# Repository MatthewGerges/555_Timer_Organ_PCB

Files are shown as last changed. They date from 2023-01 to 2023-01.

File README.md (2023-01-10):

# 555 Timer Piano PCB


- This project was created using Altium CircuitMaker. All design files including the 3D model can be viewed here: 
https://365.altium.com/files/4F6F4C2E-66A3-4076-8B9E-142F36BC1FB1

- This PCB uses a 555 timer to generate sounds part of the diatonic scale on a piano. 
- One of the resistors used to set the frequency of the clock signal is fixed. 
- The resistor whose connected momentary switch is pressed acts as the other element that dictates the frequency of the clock signal. 
- The output of the clock then feeds to an NPN transistor that acts as an audio amplifier. 
- The amplified signal is then run through a speaker so the user can hear the piano note.

Video Demo: 
https://www.loom.com/share/736d4f29e4ee4808afbea287dc831833

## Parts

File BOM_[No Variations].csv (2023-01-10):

Comment | Description | Designator | Quantity | Man. Part Number
Memory Protection Devices BH9VPC | 9V cell holder w/ PC pins (80 pcs per tray) |  | 1
FG11X7R1C226MRT06 | Commercial Grade, Halogen Free Dipped Radial / Ammo Pack | C1 | 1
Panasonic ECA-1HM100B | Cap Aluminum 10uF 50V 20% (2.5v6 or 2.5 X 11mm) Radial Aluminum Cylindrical Can p=5x6 mm 65mA 2000 hr 85°C Ammo Pack | C2 | 1
Vishay A104K15X7RF5UAA | Cap Ceramic 0.1uF 50V X7R 10% Axial 125°C Ammo Pack | C3, C4, C5, C6 | 4
Panasonic ECA-1HM100B 100mF | Cap Aluminum 10uF 50V 20% (2.5v6 or 2.5 X 11mm) Radial Aluminum Cylindrical Can p=5x6 mm 65mA 2000 hr 85°C Ammo Pack | C7 | 1
100 mF | Cap Aluminum 10uF 50V 20% (2.5v6 or 2.5 X 11mm) Radial Aluminum Cylindrical Can p=5x6 mm 65mA 2000 hr 85°C Ammo Pack | C8 | 1
Lumex SSL-LX5093PGD | Green 5 mm 60° Diffused 30 mcd 2.2 V Through Hole LED - T-1¾ | D1 | 1
"Flyback/Inductive Kick Diode" | 1N4001 Series 1 A 400 V Through-Hole Rectifying Diode - DO-41 | D2 | 1
Fairchild Semiconductor KSP43TA | Trans GP BJT NPN 200V 0.5A 3-Pin TO-92 Ammo | Q1 | 1
Yageo CFR-25JR-52-270R | CFR Series 0.25 W 470 Ohm ±5 % -350 to 500 ppm/°C Carbon Film Resistor | R1 | 1
27.7k | CFR Series 0.25 W 470 Ohm ±5 % -350 to 500 ppm/°C Carbon Film Resistor | R2 | 1
25.5k | CFR Series 0.25 W 470 Ohm ±5 % -350 to 500 ppm/°C Carbon Film Resistor | R3 | 1
24.0k | CFR Series 0.25 W 470 Ohm ±5 % -350 to 500 ppm/°C Carbon Film Resistor | R4 | 1
22.1 | CFR Series 0.25 W 470 Ohm ±5 % -350 to 500 ppm/°C Carbon Film Resistor | R5 | 1
21.0 | CFR Series 0.25 W 470 Ohm ±5 % -350 to 500 ppm/°C Carbon Film Resistor | R6 | 1
20.0 | CFR Series 0.25 W 470 Ohm ±5 % -350 to 500 ppm/°C Carbon Film Resistor | R7 | 1
18.7 | CFR Series 0.25 W 470 Ohm ±5 % -350 to 500 ppm/°C Carbon Film Resistor | R8 | 1
17.8 | CFR Series 0.25 W 470 Ohm ±5 % -350 to 500 ppm/°C Carbon Film Resistor | R9 | 1
16.5 | CFR Series 0.25 W 470 Ohm ±5 % -350 to 500 ppm/°C Carbon Film Resistor | R10 | 1
16.0 | CFR Series 0.25 W 470 Ohm ±5 % -350 to 500 ppm/°C Carbon Film Resistor | R11 | 1
15.0 | CFR Series 0.25 W 470 Ohm ±5 % -350 to 500 ppm/°C Carbon Film Resistor | R12 | 1
14.0 | CFR Series 0.25 W 470 Ohm ±5 % -350 to 500 ppm/°C Carbon Film Resistor | R13 | 1
1.4k | CFR Series 0.25 W 470 Ohm ±5 % -350 to 500 ppm/°C Carbon Film Resistor | R14 | 1
10k | CFR Series 0.25 W 470 Ohm ±5 % -350 to 500 ppm/°C Carbon Film Resistor | R15 | 1
1k | CFR Series 0.25 W 470 Ohm ±5 % -350 to 500 ppm/°C Carbon Film Resistor | R16 | 1
TSW-102-22-L-S-RA | 0.025" SQ Post Header, Through-hole, Right Angle, -55 to 125 degC, 2.54 mm Pitch, 2-Pin, Male, RoHS | SPK1 | 1
E-Switch EG1218 | Slide Switch, 500 V, -20 to 70 degC, 3-Pin THD, RoHS | SW1 | 1
Panasonic EVQ-21405R | Switch Tactile N.O. SPST Round Button PC Pins 0.02A 15VDC 1.3N Thru-Hole Radial T/R | SW2, SW3, SW4, SW5, SW6, SW7, SW8, SW9, SW10, SW11, SW12, SW13 | 12
2x2mm-pad | Raychem; SMT Circuit probe pad, 0805, 0R0 RCT | TP_5V, TP_GND1, TP_SIG | 3
MCP1702-5002E/TO | 250 mA Low Quiescent Current LDO Regulator, 3-Pin TO-92, Extended TemperatureBAG | U1 | 1
555 Custom | timer | U2 | 1

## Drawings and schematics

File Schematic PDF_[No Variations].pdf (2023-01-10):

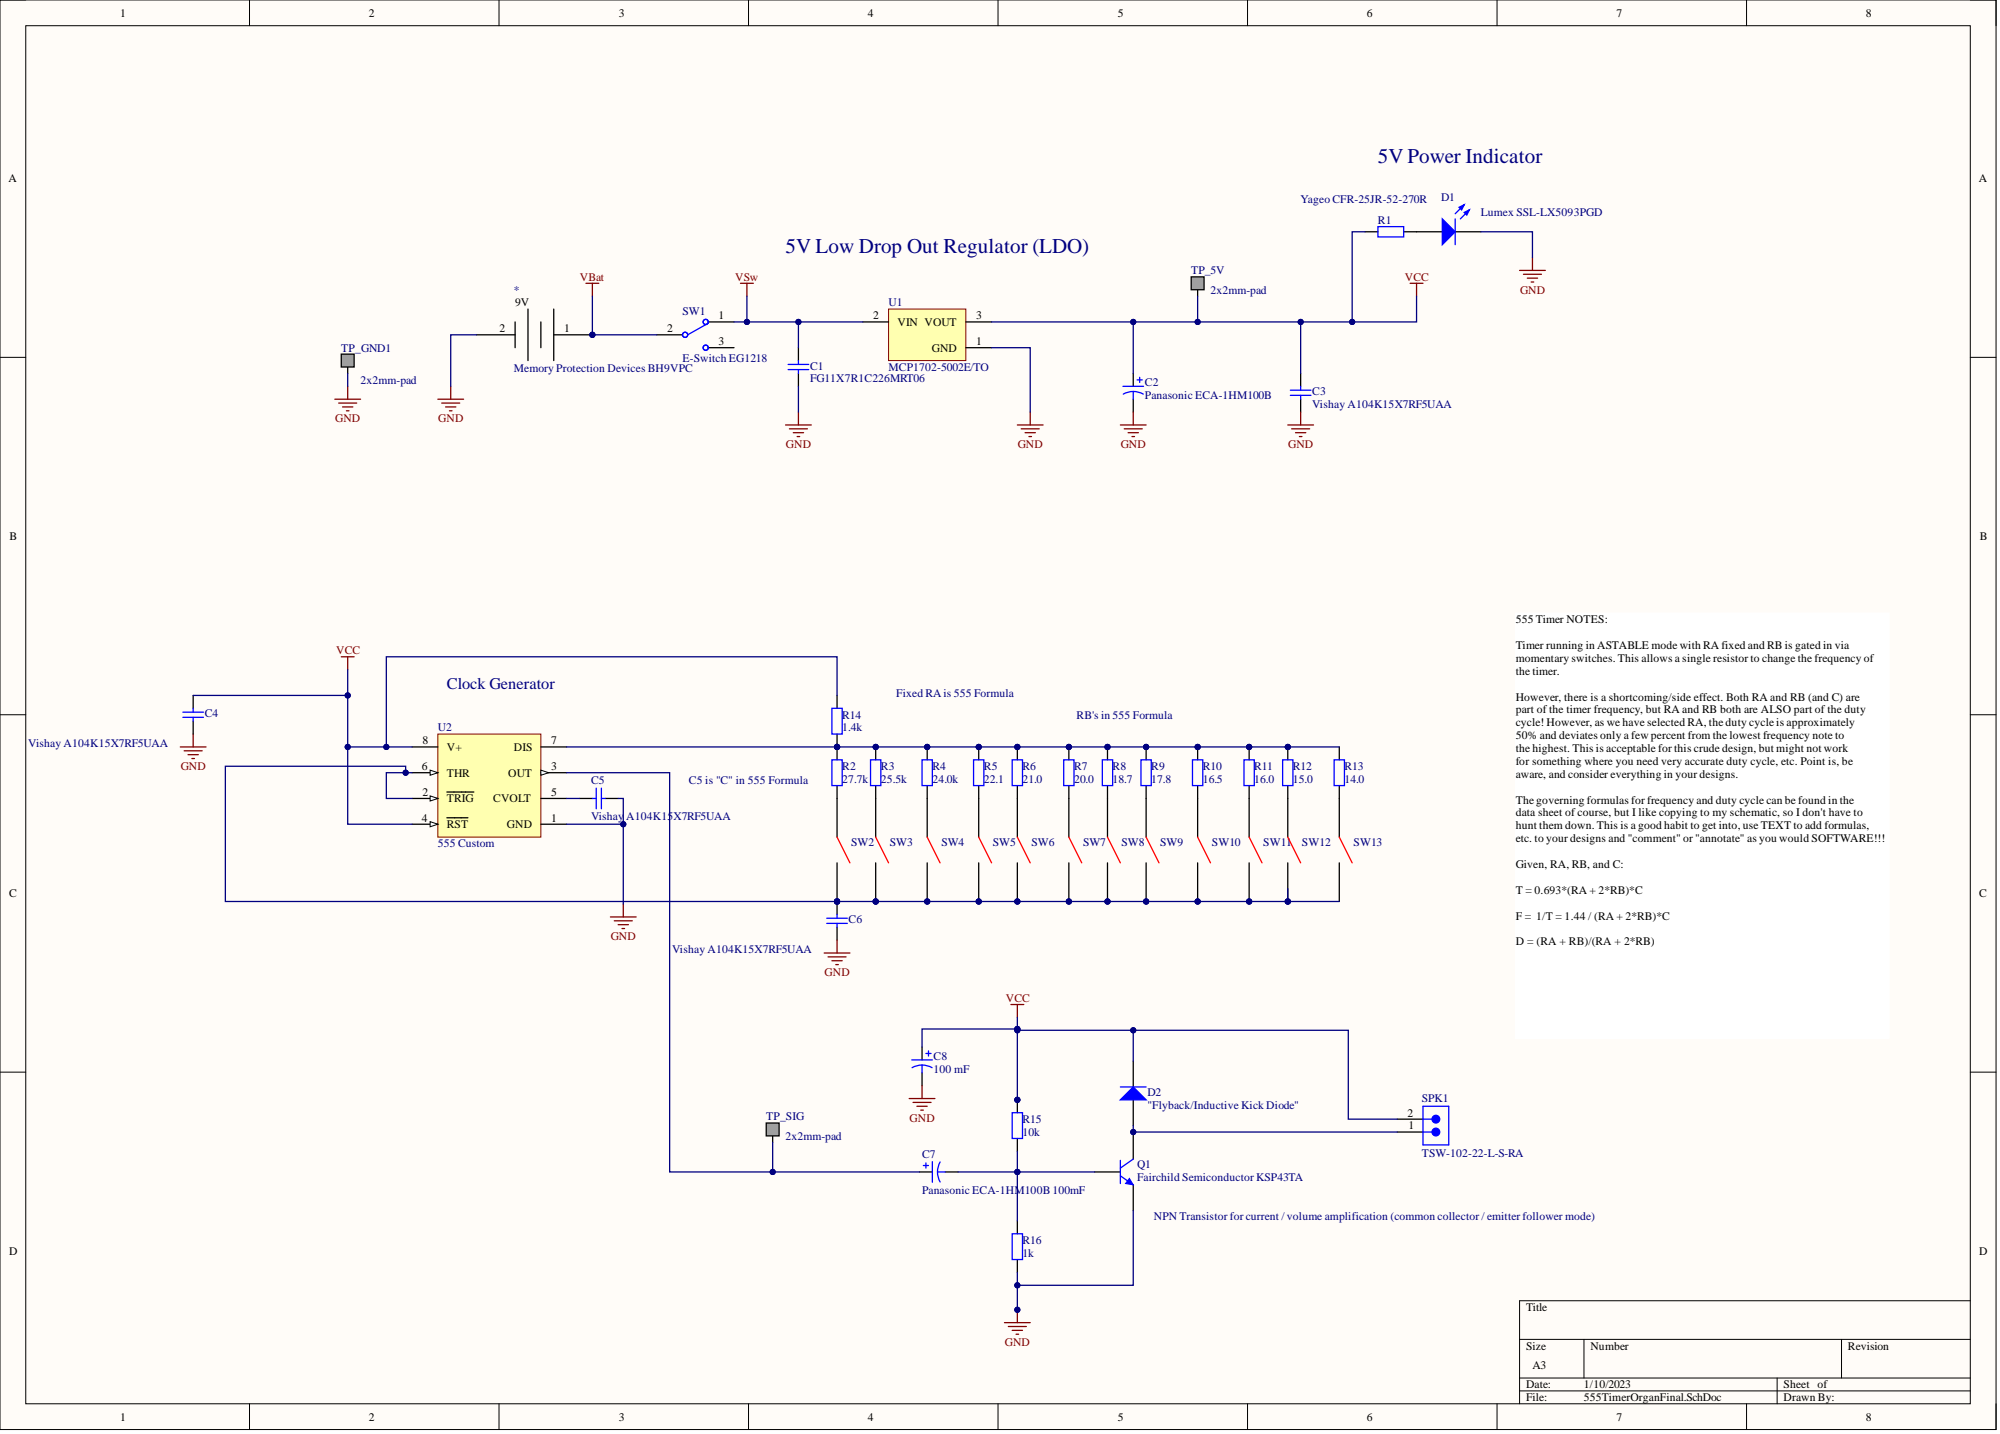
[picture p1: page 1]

5V Low Drop Out Regulator (LDO)

Timer running in ASTABLE mode with RA fixed and RB is gated in via
momentary switches. This allows a single resistor to change the frequency of
the timer.

Fixed RA is 555 Formula

However, there is a shortcoming/side effect. Both RA and RB (and C) are
part of the timer frequency, but RA and RB both are ALSO part of the duty
cycle! However, as we have selected RA, the duty cycle is approximately
50% and deviates only a few percent from the lowest frequency note to
the highest. This is acceptable for this crude design, but might not work
for something where you need very accurate duty cycle, etc. Point is, be
aware, and consider everything in your designs.

THR 6 OUT CVOLT | 3

TRIG 2 | 5 | Vishay A104K15X7RF5UAA

The governing formulas for frequency and duty cycle can be found in the
data sheet of course, but I like copying to my schematic, so I don't have to
hunt them down. This is a good habit to get into, use TEXT to add formulas,
etc. to your designs and "comment" or "annotate" as you would SOFTWARE!!!

Given, RA, RB, and C:

"Flyback/Inductive Kick Diode"

NPN Transistor for current / volume amplification (common collector / emitter follower mode)

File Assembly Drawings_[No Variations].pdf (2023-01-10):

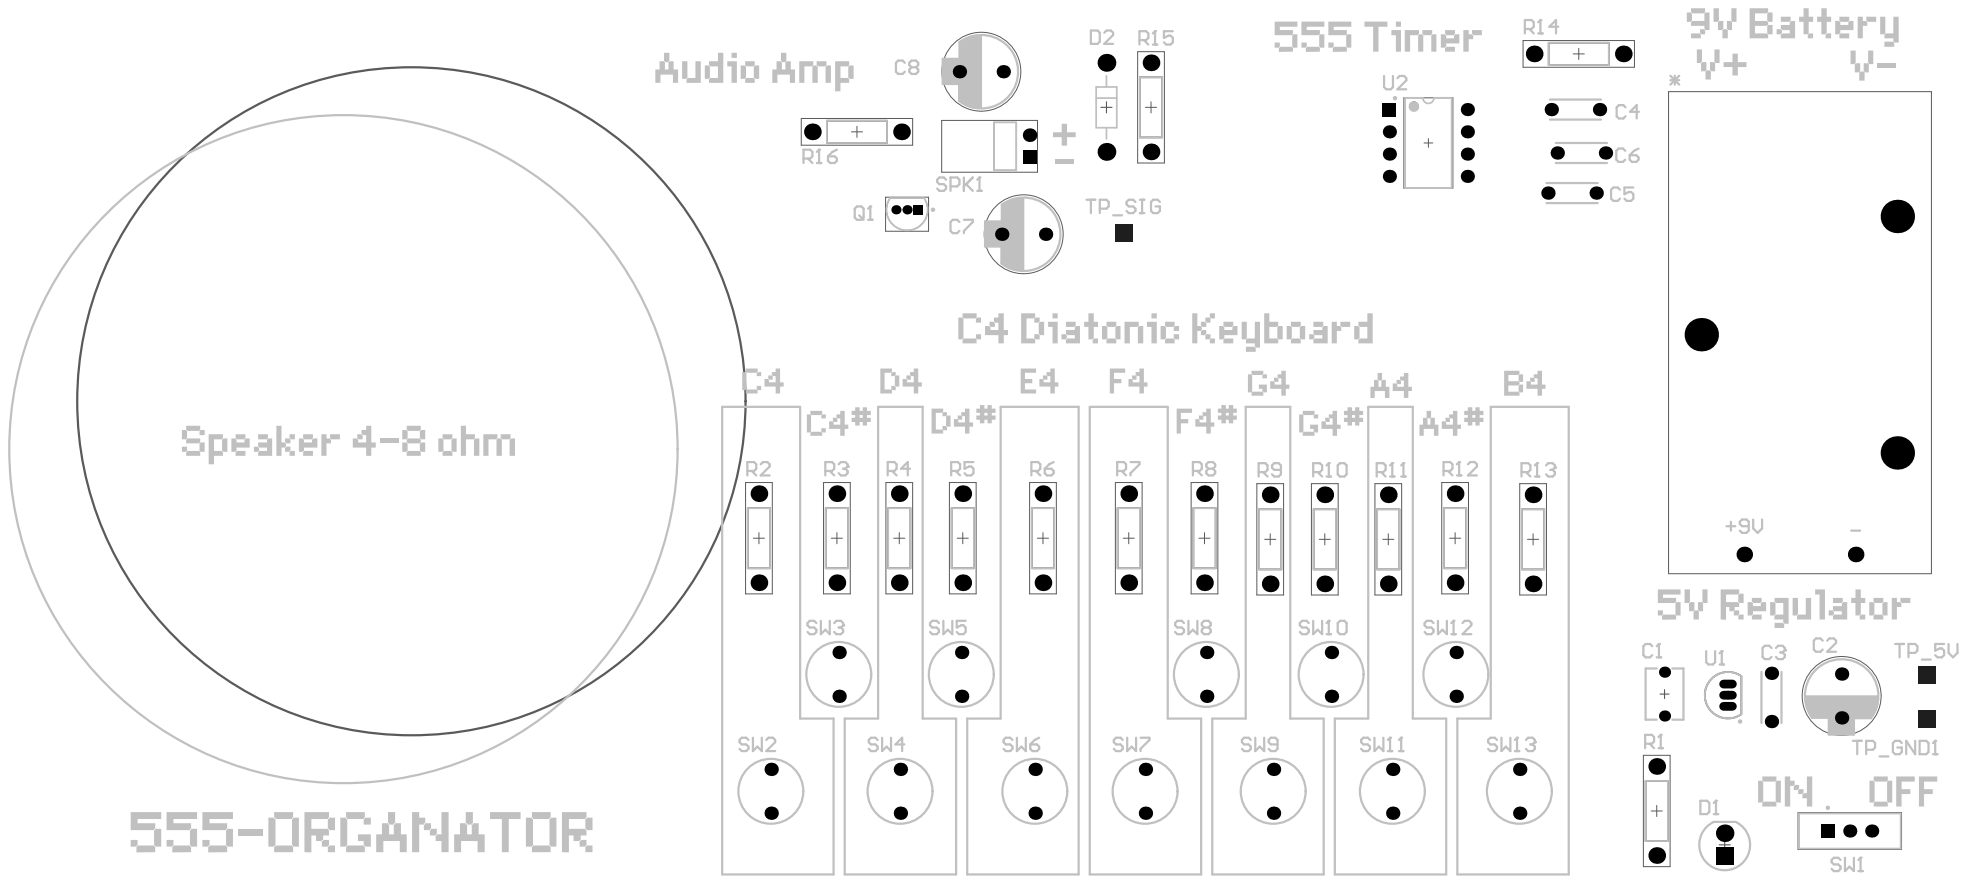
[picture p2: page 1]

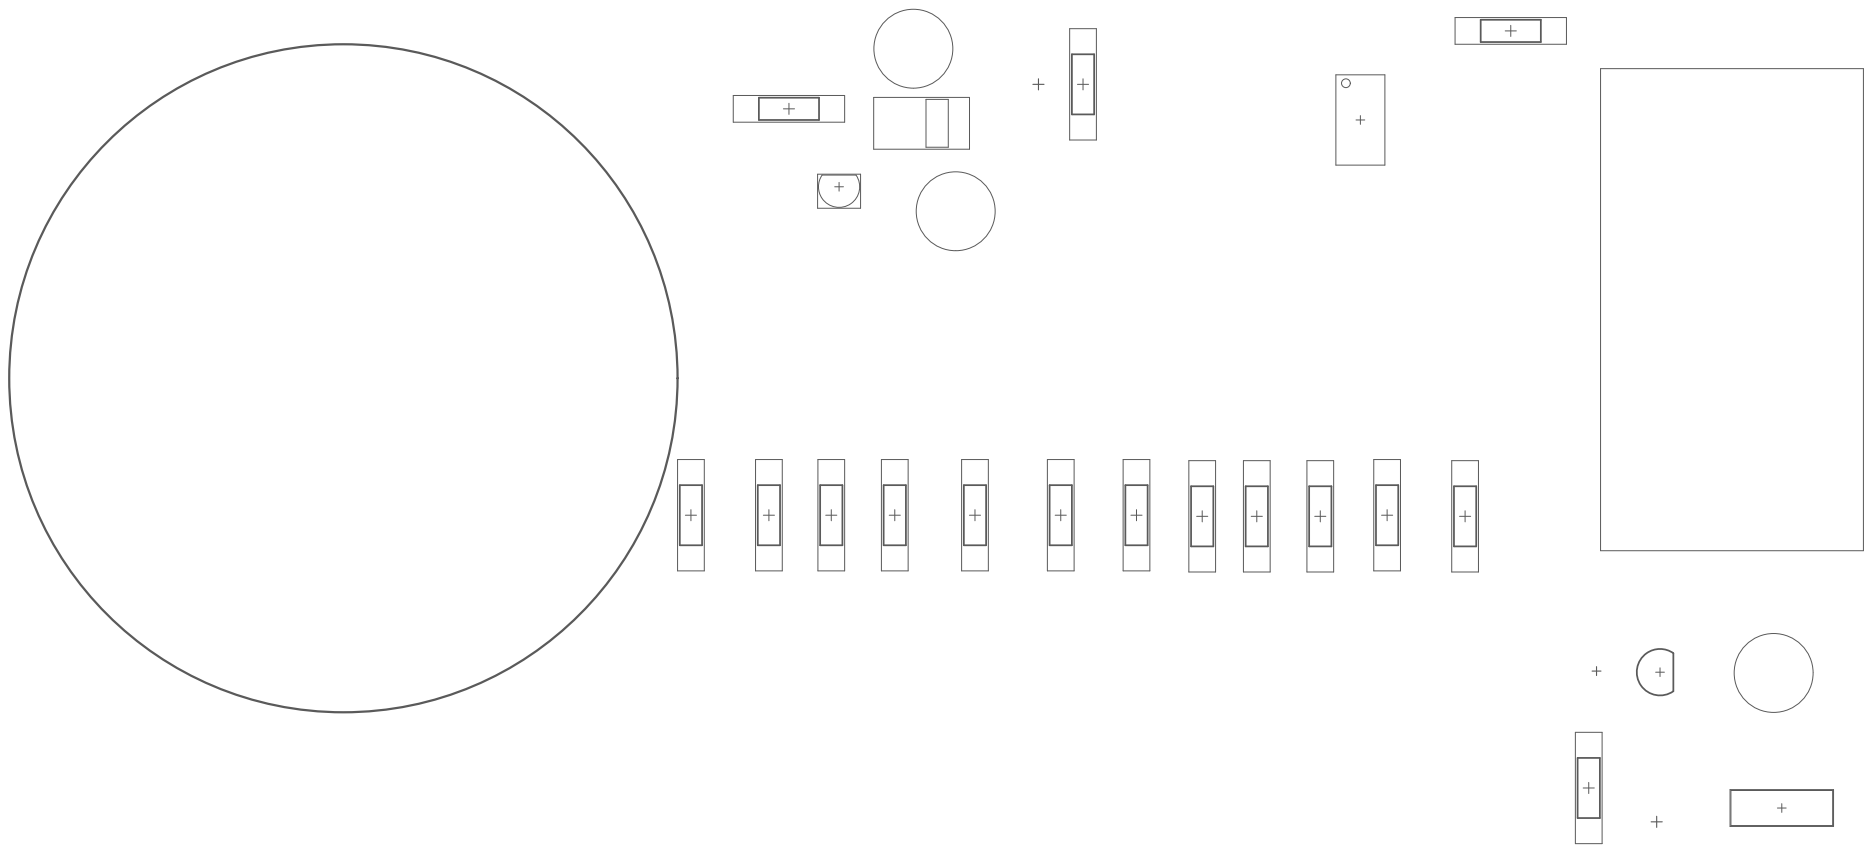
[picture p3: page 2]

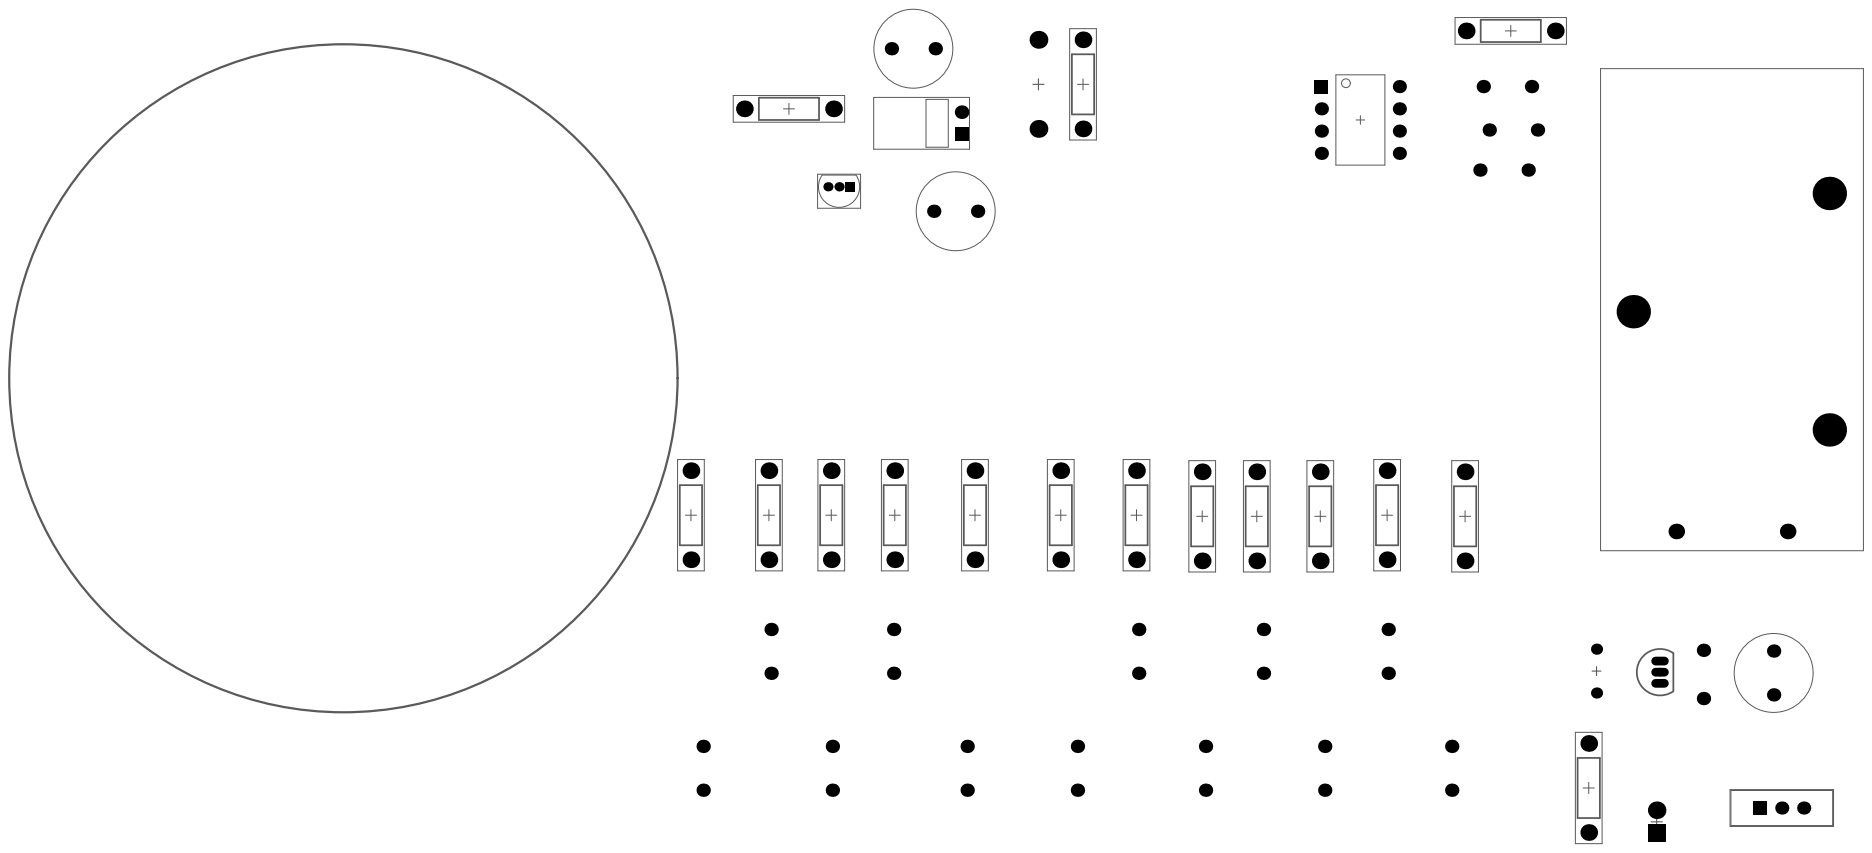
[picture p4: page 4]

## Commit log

2023-01-10 adding all files
    [BOM_[No Variations].csv]
2023-01-10 unzipped gerber file
    [TimerOrganPCB_Copper_Signal_Bot.gbr, TimerOrganPCB_Copper_Signal_Top.gbr, TimerOrganPCB_Legend_Top.gbr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]
